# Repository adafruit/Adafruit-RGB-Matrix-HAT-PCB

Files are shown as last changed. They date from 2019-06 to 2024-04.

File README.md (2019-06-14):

## Adafruit RGB Matrix HAT PCB

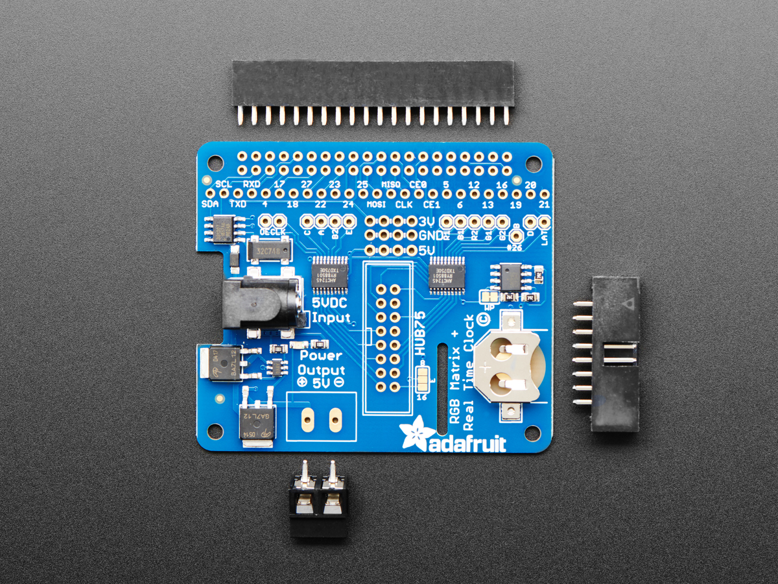
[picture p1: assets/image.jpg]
<a href="http://www.adafruit.com/products/1932"><br/>
Click here to purchase one from the Adafruit shop</a>

PCB files for the Adafruit RGB Matrix HAT. Format is EagleCAD schematic and board layout
* https://www.adafruit.com/product/2345

### DESCRIPTION
You can now create a dazzling display with your Raspberry Pi Model Zero/A+/B+/Pi 2 or Pi 3 with the Adafruit RGB Matrix HAT. This HAT plugs into your Pi and makes it super easy to control RGB matrices such as those we stock in the shop and create a colorful scrolling display or mini LED wall with ease.

This HAT is our finest to date, full of some really great circuitry. Let me break it down for you:

Simple design - plug in power, plug in IDC cable, run our Python code!
Power protection circuitry - you can plug a 5V 4A wall adapter into the HAT and it will automatically protect against negative, over or under-voltages! Yay for no accidental destruction of your setup.
Onboard level shifters to convert the RasPi's 3.3V to 5.0V logic for clean and glitch free matrix driving
DS1307 Real Time Clock can keep track of time for the Pi even when it is rebooted or powered down, to make for really nice time displays
Works with any of our 16x32, 32x32, 32x64 or 64x64 RGB LED Matrices with HUB75 connections. You can even chain multiple matrices together for a longer display, you can chain as many as you like but the bigger the display the harder it is on the Pi so keep that in mind! We don't recommend more than 64x128 pixel setups

As of October 2018, we now sell a version that can be used with 64x64 pixel matrices that have an 'E' address pin!

Please note: this HAT is only for use with HUB75 type RGB Matrices. Not for use with NeoPixel, DotStar, or other 'addressable' LEDs.

### License

Adafruit invests time and resources providing this open source design, please support Adafruit and open-source hardware by purchasing products from [Adafruit.com](https://www.adafruit.com)!

Creative Commons Attribution, Share-Alike license, check license.txt for more information All text above must be included in any redistribution - 
See license.txt for more information.

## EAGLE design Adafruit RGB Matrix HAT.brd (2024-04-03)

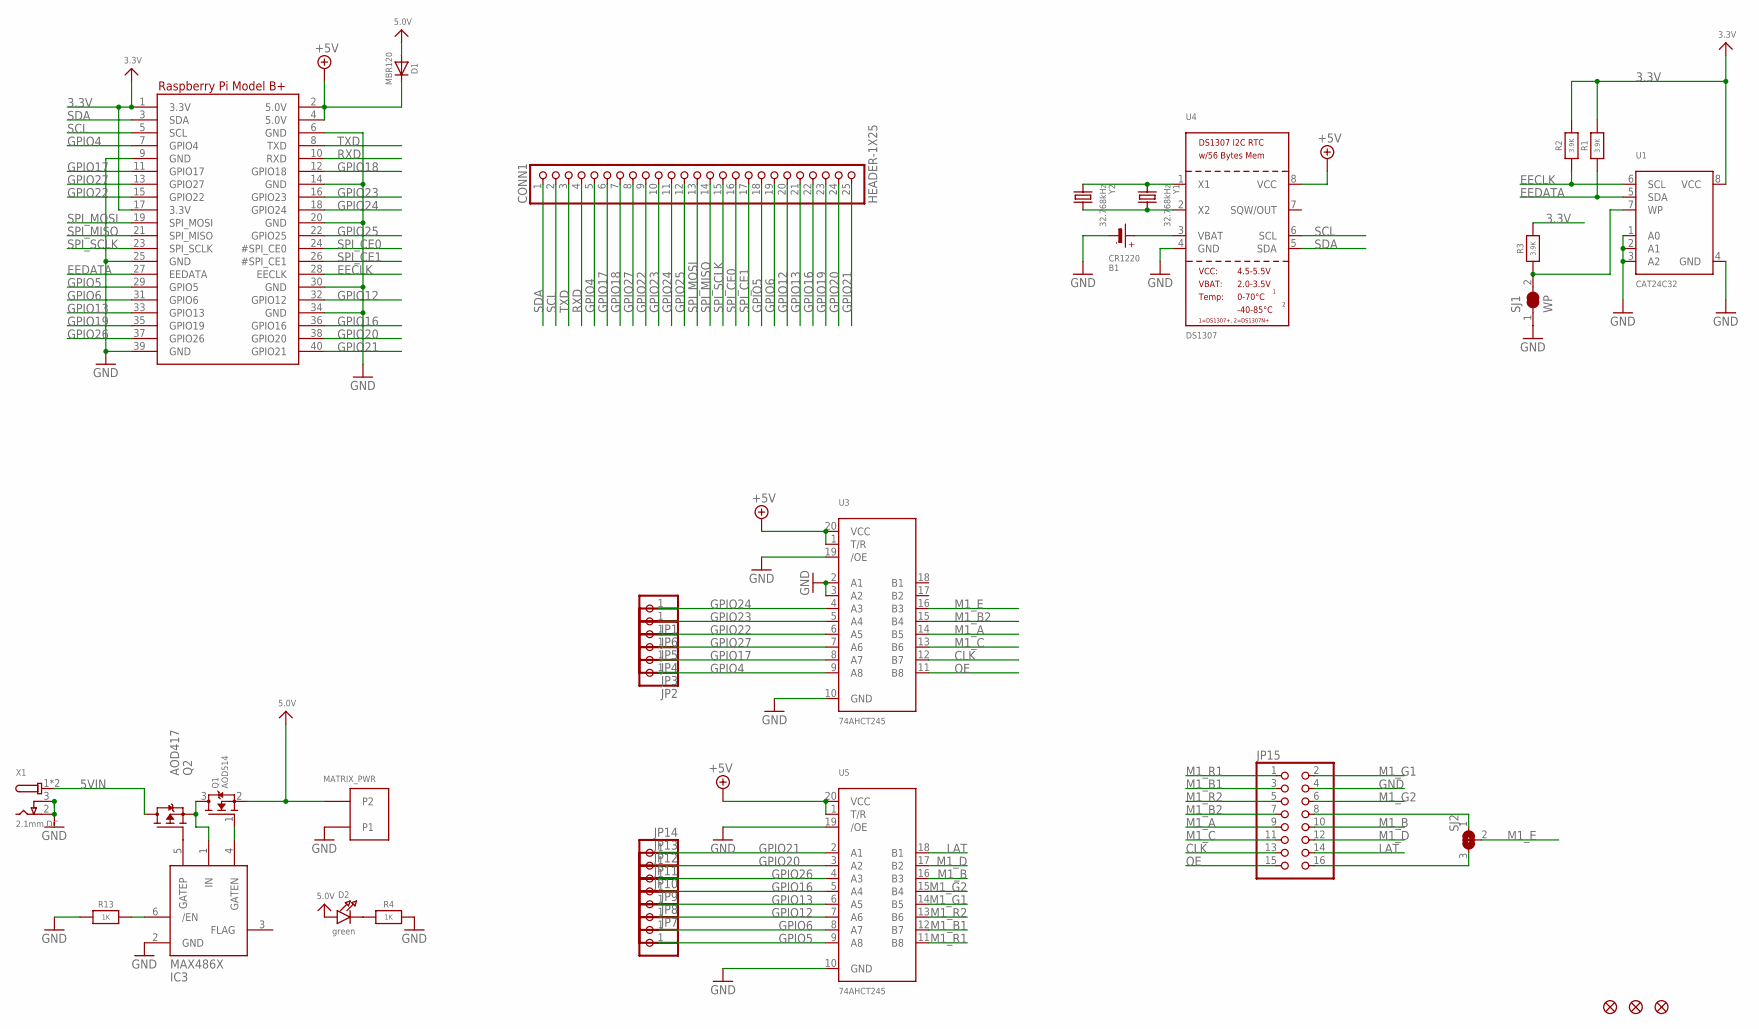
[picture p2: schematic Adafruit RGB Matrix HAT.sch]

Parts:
B1: CR1220
CONN1: HEADER-1X25; 1X25_ROUND_70MIL
D1: MBR120; SOD-123
D2: green; CHIPLED_0805_NOOUTLINE
FID1, FID2, FID3: FIDUCIAL_1MM
IC3: MAX4866T; SOT23-6
JP1, JP2, JP3, JP4, JP5, JP6, JP7, JP8, JP9, JP10, JP11, JP12, JP13, JP14: PINHD-1X1; 1X01
JP15: HEADER-2X8_SHROUDED; 2X08_SHROUDED
MATRIX_PWR: PINHEAD; TERMBLOCK508
Q1: AOD514; TO252
Q2: AOD417; TO252
R1, R2, R3: 3.9K; 0805-NO
R4, R13: 1K; 0805-NO
RPI1: RASPBERRYPI_BPLUS_HATSLOTS; PI_HAT_SLOTS
SJ1: WP; SOLDERJUMPER_CLOSEDWIRE
SJ2: SOLDERJUMPER_2WAY; SOLDERJUMPER_2WAY_OPEN_NOPASTE
U1: CAT24C32; SOIC8_150MIL
U3, U5: 74AHCT245; TSSOP20
U4: DS1307; SOIC8_150MIL
X1: 2.1mm DC; DCJACK_2MM_SMT
Y1: 32.768kHz; CRYSTAL_8X3.8
Y2: 32.768kHz; XTAL3215

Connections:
3.3V: R1.2, R2.2, R3.2, RPI1.1 (3.3V), RPI1.17 (3.3V), U1.8 (VCC)
5.0V: D1.A, D2.A, MATRIX_PWR.P$4 (P2), Q1.2 (S)
5VIN: Q2.3 (D), X1.1 (PWR), X1.1' (PWR)
+5V: D1.C, RPI1.2 (5.0V), RPI1.4 (5.0V), U3.1 (T/R), U3.20 (VCC), U4.8 (VCC), U5.1 (T/R), U5.20 (VCC)
CLK: JP15.13, U3.12 (B7)
EECLK: R2.1, RPI1.28 (EECLK), U1.6 (SCL)
EEDATA: R1.1, RPI1.27 (EEDATA), U1.5 (SDA)
GND: B1.-, IC3.2 (GND), JP15.4, MATRIX_PWR.P$3 (P1), R4.2, R13.1, RPI1.6 (GND), RPI1.9 (GND), RPI1.14 (GND), RPI1.20 (GND), RPI1.25 (GND), RPI1.30 (GND), RPI1.34 (GND), RPI1.39 (GND), SJ1.1, U1.1 (A0), U1.2 (A1), U1.3 (A2), U1.4 (GND), U3.2 (A1), U3.3 (A2), U3.10 (GND), U3.19 (/OE), U4.4 (GND), U5.10 (GND), U5.19 (/OE), X1.2 (GND), X1.3 (GNDBREAK)
GPIO4: CONN1.5, JP2.1, RPI1.7 (GPIO4), U3.9 (A8)
GPIO5: CONN1.18, JP7.1, RPI1.29 (GPIO5), U5.9 (A8)
GPIO6: CONN1.19, JP8.1, RPI1.31 (GPIO6), U5.8 (A7)
GPIO12: CONN1.20, JP9.1, RPI1.32 (GPIO12), U5.7 (A6)
GPIO13: CONN1.21, JP10.1, RPI1.33 (GPIO13), U5.6 (A5)
GPIO16: CONN1.22, JP11.1, RPI1.36 (GPIO16), U5.5 (A4)
GPIO17: CONN1.6, JP3.1, RPI1.11 (GPIO17), U3.8 (A7)
GPIO18: CONN1.7, RPI1.12 (GPIO18)
GPIO19: CONN1.23, RPI1.35 (GPIO19)
GPIO20: CONN1.24, JP13.1, RPI1.38 (GPIO20), U5.3 (A2)
GPIO21: CONN1.25, JP14.1, RPI1.40 (GPIO21), U5.2 (A1)
GPIO22: CONN1.9, JP5.1, RPI1.15 (GPIO22), U3.6 (A5)
GPIO23: CONN1.10, JP6.1, RPI1.16 (GPIO23), U3.5 (A4)
GPIO24: CONN1.11, JP1.1, RPI1.18 (GPIO24), U3.4 (A3)
GPIO25: CONN1.12, RPI1.22 (GPIO25)
GPIO26: JP12.1, RPI1.37 (GPIO26), U5.4 (A3)
GPIO27: CONN1.8, JP4.1, RPI1.13 (GPIO27), U3.7 (A6)
LAT: JP15.14, U5.18 (B1)
M1_A: JP15.9, U3.14 (B5)
M1_B: JP15.10, U5.16 (B3)
M1_B1: JP15.3, U5.12 (B7)
M1_B2: JP15.7, U3.15 (B4)
M1_C: JP15.11, U3.13 (B6)
M1_D: JP15.12, U5.17 (B2)
M1_E: SJ2.2, U3.16 (B3)
M1_E': JP15.8, SJ2.1
M1_E'': JP15.16, SJ2.3
M1_G1: JP15.2, U5.14 (B5)
M1_G2: JP15.6, U5.15 (B4)
M1_R1: JP15.1, U5.11 (B8)
M1_R2: JP15.5, U5.13 (B6)
unnamed: IC3.6 (/EN), R13.2
unnamed: U4.1 (X1), Y1.P$1 (1), Y2.P$1 (1)
unnamed: U4.2 (X2), Y1.P$4 (2), Y2.P$2 (2)
unnamed: D2.C, R4.1
unnamed: IC3.1 (IN), Q1.3 (D), Q2.2 (S)
unnamed: IC3.4 (GATEN), Q1.1 (G)
unnamed: IC3.5 (GATEP), Q2.1 (G)
unnamed: B1.+$1 (+), B1.+$2 (+), U4.3 (VBAT)
unnamed: R3.1, SJ1.2, U1.7 (WP)
OE: JP15.15, U3.11 (B8)
RXD: CONN1.4, RPI1.10 (RXD)
SCL: CONN1.2, RPI1.5 (SCL), U4.6 (SCL)
SDA: CONN1.1, RPI1.3 (SDA), U4.5 (SDA)
SPI_CE0: CONN1.16, RPI1.24 (#SPI_CE0)
SPI_CE1: CONN1.17, RPI1.26 (#SPI_CE1)
SPI_MISO: CONN1.14, RPI1.21 (SPI_MISO)
SPI_MOSI: CONN1.13, RPI1.19 (SPI_MOSI)
SPI_SCLK: CONN1.15, RPI1.23 (SPI_SCLK)
TXD: CONN1.3, RPI1.8 (TXD)

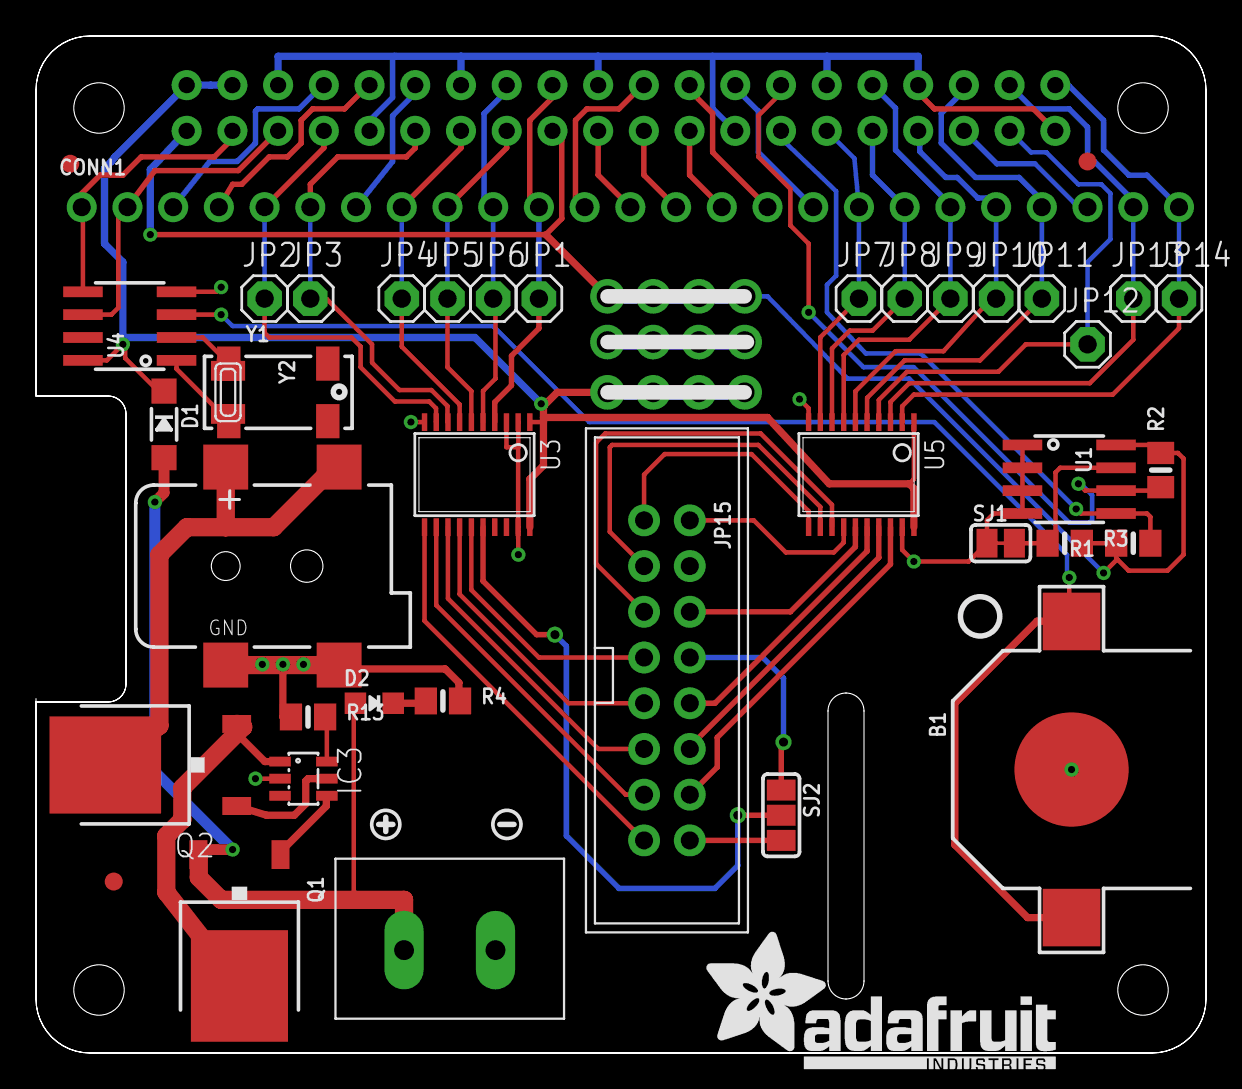
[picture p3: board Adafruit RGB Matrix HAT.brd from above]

Board: 2 copper layers, 65.0 x 56.5 mm, 97 parts (0 on the bottom side), 58 nets.

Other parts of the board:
PLABEL0: PLABEL0
PLABEL1: PLABEL1
PLABEL2: PLABEL2
PLABEL3: PLABEL3
PLABEL4: PLABEL4
PLABEL5: PLABEL5
PLABEL6: PLABEL6
PLABEL7: PLABEL7
PLABEL8: PLABEL8
PLABEL9: PLABEL9
PLABEL10: PLABEL10
PLABEL11: PLABEL11
PLABEL12: PLABEL12
PLABEL13: PLABEL13
PLABEL14: PLABEL14
PLABEL15: PLABEL15
PLABEL16: PLABEL16
PLABEL17: PLABEL17
PLABEL18: PLABEL18
PLABEL19: PLABEL19
PLABEL20: PLABEL20
PLABEL21: PLABEL21
PLABEL22: PLABEL22
PLABEL23: PLABEL23
PLABEL24: PLABEL24
PLABEL25: PLABEL25
PLABEL26: PLABEL26
PLABEL27: PLABEL27
PLABEL28: PLABEL28
PLABEL29: PLABEL29
PLABEL30: PLABEL30
PLABEL31: PLABEL31
PLABEL32: PLABEL32
PLABEL33: PLABEL33
PLABEL34: PLABEL34
PLABEL35: PLABEL35
PLABEL36: PLABEL36
PLABEL37: PLABEL37
PLABEL38: PLABEL38
PLABEL39: PLABEL39
PLABEL40: PLABEL40
PLABEL41: PLABEL41
PLABEL42: PLABEL42
PLABEL43: PLABEL43
PLABEL44: PLABEL44
PLABEL45: PLABEL45
PLABEL46: PLABEL46
PLABEL47: PLABEL47
PLABEL48: PLABEL48
PLABEL49: PLABEL49
PLABEL50: PLABEL50
PLABEL51: PLABEL51
U$3: PCBFEAT-REV-056
U$10: SYMBOL_PLUS
U$11: SYMBOL_MINUS
U$12: ADAFRUIT_TEXT_20MM

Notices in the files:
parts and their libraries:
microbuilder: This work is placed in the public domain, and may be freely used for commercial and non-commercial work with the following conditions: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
